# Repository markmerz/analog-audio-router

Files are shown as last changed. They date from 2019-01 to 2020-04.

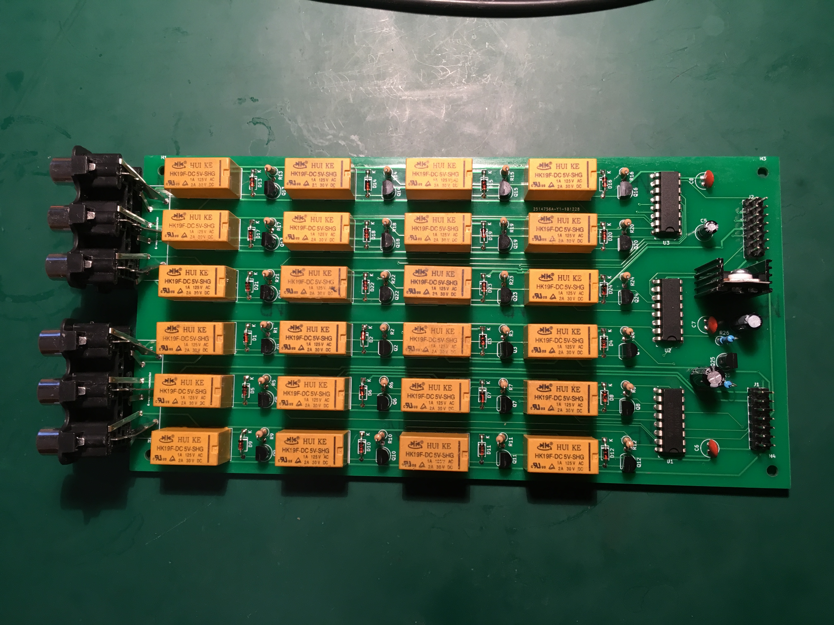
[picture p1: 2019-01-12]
showoff/assembled-audiorouter-board.jpg

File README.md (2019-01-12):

# analog-audio-router
Schematics and firmware for analog line level audio router/switchbox.

When You have some number of older audio gear then inputs count of power amplifier comes an issue. 
It would be nice to have some kind of switchbox for RCA inputs. There is not something like that in
the market, so i'm building one by myself. With blackjack!

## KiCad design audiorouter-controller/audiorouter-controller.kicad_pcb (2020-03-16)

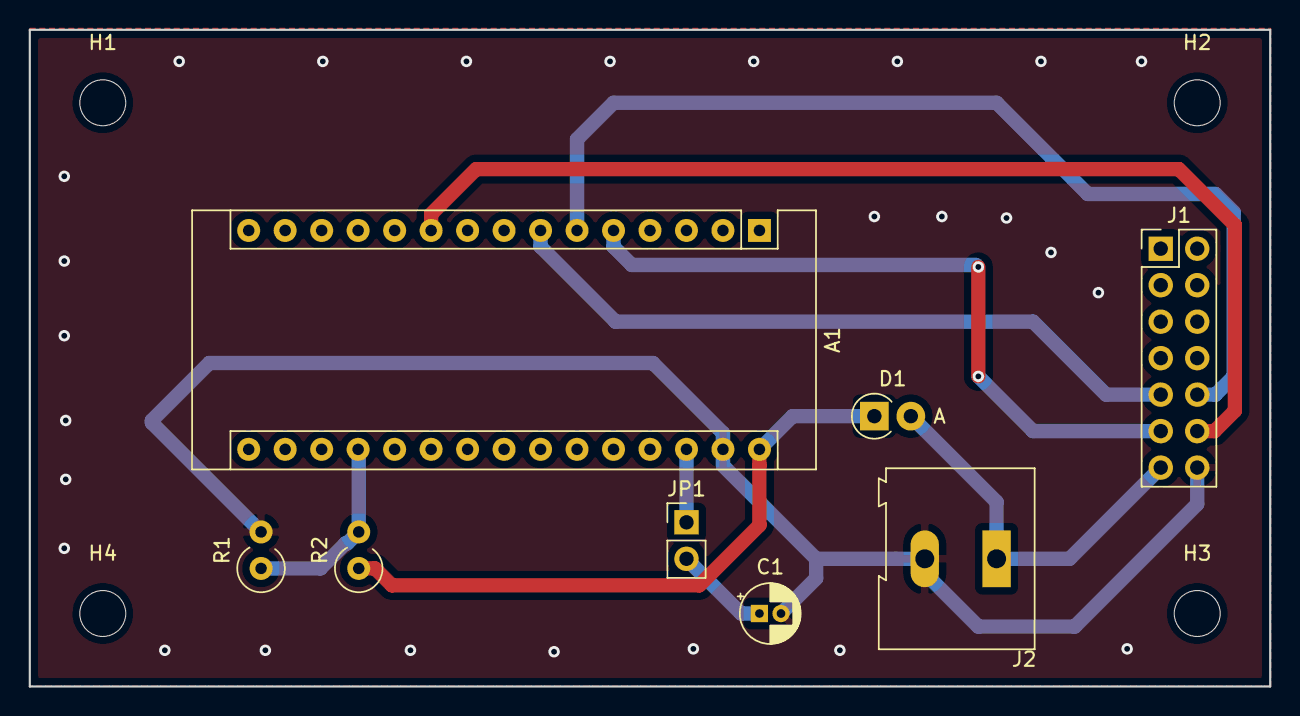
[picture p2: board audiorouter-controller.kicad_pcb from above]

Board: 2 copper layers, 86.4 x 45.7 mm, 12 parts (0 on the bottom side), 10 nets.

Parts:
A1: Arduino_Nano_v3.x; Arduino_Nano
C1: 10u; CP_Radial_D4.0mm_P1.50mm
D1: N4007; D_T-1_P2.54mm_Vertical_AnodeUp
H1, H2, H3, H4: MountingHole; MountingHole_3.2mm_M3
J1: ToBoards; PinHeader_2x07_P2.54mm_Vertical
J2: PowerIn; TerminalBlock_Altech_AK300-2_P5.00mm
JP1: progEnable; PinHeader_1x02_P2.54mm_Vertical
R1, R2: 6.8k; R_Axial_DIN0309_L9.0mm_D3.2mm_P2.54mm_Vertical

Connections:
GND: A1.29, C1.2, J1.14, J2.2, R1.2
unnamed: A1.28, JP1.1
unnamed: A1.30, D1.1, R2.1
unnamed: C1.1, JP1.2
OutputEnable: A1.10, J1.12
PowerIn: D1.2, J1.13, J2.1
PowerMeasure: A1.19, R1.1, R2.2
RClock: A1.6, J1.10
SerialClock: A1.5, J1.11
SerialOut: A1.7, J1.9

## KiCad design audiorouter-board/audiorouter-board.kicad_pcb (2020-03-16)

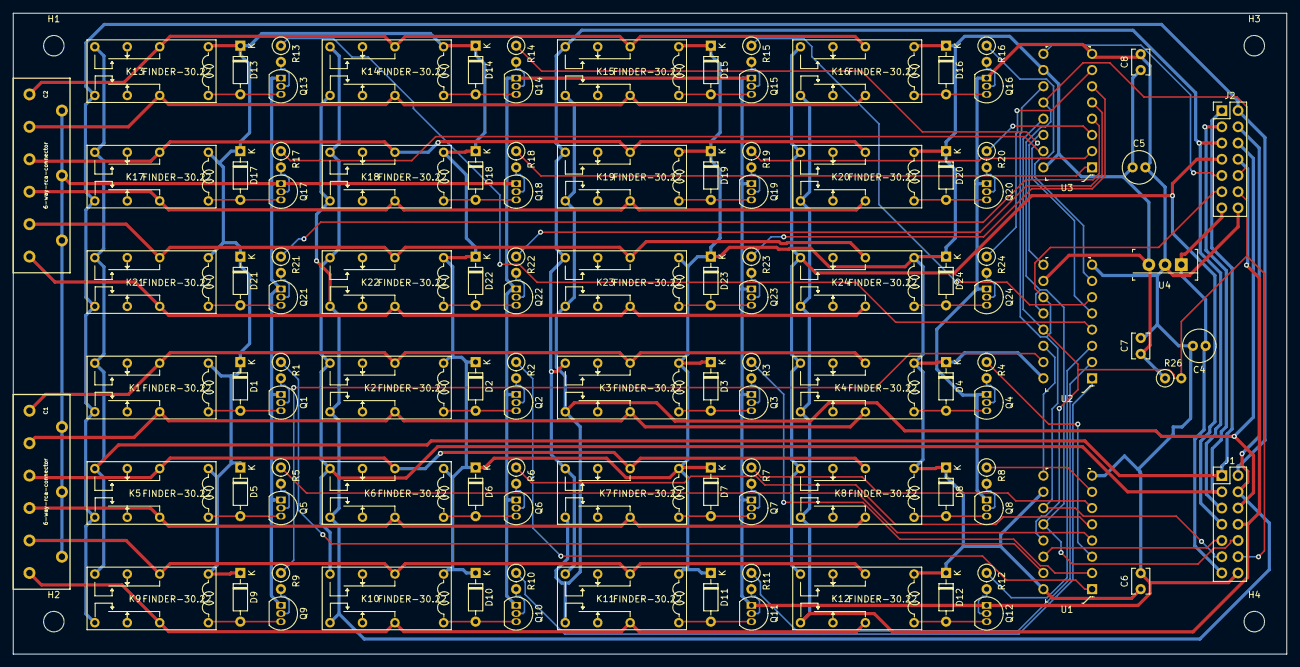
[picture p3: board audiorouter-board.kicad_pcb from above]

Board: 2 copper layers, 199.4 x 100.3 mm, 114 parts (0 on the bottom side), 102 nets.

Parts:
C1, C2: 6-way-rca-connector; 6-way-rca-connector-on-edge
C4, C5: 10u; C_Radial_D5.0mm_H11.0mm_P2.00mm
C6, C7, C8: 10n; C_Disc_D3.8mm_W2.6mm_P2.50mm
D1, D2, D3, D4, D5, D6, D7, D8, D9, D10, D11, D12, D13, D14, D15, D16, D17, D18, D19, D20, D21, D22, D23, D24: 1N914; D_DO-35_SOD27_P7.62mm_Horizontal
H1, H2, H3, H4: MountingHole; MountingHole_3.2mm_M3
J1: Input_Ribbon_Connector; PinHeader_2x07_P2.54mm_Vertical
J2: Output_Ribbon_Connector; PinHeader_2x07_P2.54mm_Vertical
K1, K2, K3, K4, K5, K6, K7, K8, K9, K10, K11, K12, K13, K14, K15, K16, K17, K18, K19, K20, K21, K22, K23, K24: FINDER-30.22; RY12w-k_bigger_holes
Q1, Q2, Q3, Q4, Q5, Q6, Q7, Q8, Q9, Q10, Q11, Q12, Q13, Q14, Q15, Q16, Q17, Q18, Q19, Q20, Q21, Q22, Q23, Q24: PN2222A; TO-92_Inline
R1, R2, R3, R4, R5, R6, R7, R8, R9, R10, R11, R12, R13, R14, R15, R16, R17, R18, R19, R20, R21, R22, R23, R24: 1k; R_Axial_DIN0207_L6.3mm_D2.5mm_P2.54mm_Vertical
R26: 10k; R_Axial_DIN0207_L6.3mm_D2.5mm_P2.54mm_Vertical
U1, U2, U3: 74HC595; DIP-16_W7.62mm
U4: L7805; TO-220-3

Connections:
GND: C1.2, C1.5, C1.8, C2.2, C2.5, C2.8, C4.2, C5.2, C6.2, C7.2, C8.2, J1.14, J2.14, Q1.1, Q2.1, Q3.1, Q4.1, Q5.1, Q6.1, Q7.1, Q8.1, Q9.1, Q10.1, Q11.1, Q12.1, Q13.1, Q14.1, Q15.1, Q16.1, Q17.1, Q18.1, Q19.1, Q20.1, Q21.1, Q22.1, Q23.1, Q24.1, U1.8, U2.8, U3.8, U4.2
IN_1_B_1: R1.1, U1.15
IN_1_B_2: R2.1, U1.1
IN_1_B_3: R3.1, U1.2
IN_1_B_4: R4.1, U1.3
IN_2_B_1: R5.1, U1.4
IN_2_B_2: R6.1, U1.5
IN_2_B_3: R7.1, U1.6
IN_2_B_4: R8.1, U1.7
IN_3_B_1: R9.1, U2.15
IN_3_B_2: R10.1, U2.1
IN_3_B_3: R11.1, U2.2
IN_3_B_4: R12.1, U2.3
IN_4_B_1: R13.1, U2.4
IN_4_B_2: R14.1, U2.5
IN_4_B_3: R15.1, U2.6
IN_4_B_4: R16.1, U2.7
IN_5_B_1: R17.1, U3.15
IN_5_B_2: R18.1, U3.1
IN_5_B_3: R19.1, U3.2
IN_5_B_4: R20.1, U3.3
IN_6_B_1: R21.1, U3.4
IN_6_B_2: R22.1, U3.5
IN_6_B_3: R23.1, U3.6
IN_6_B_4: R24.1, U3.7
unnamed: C1.1, K1.21, K2.21, K3.21, K4.21
unnamed: C1.3, K1.11, K2.11, K3.11, K4.11
unnamed: C1.4, K5.21, K6.21, K7.21, K8.21
unnamed: C1.6, K5.11, K6.11, K7.11, K8.11
unnamed: C1.7, K9.21, K10.21, K11.21, K12.21
unnamed: C1.9, K9.11, K10.11, K11.11, K12.11
unnamed: C2.1, K13.21, K14.21, K15.21, K16.21
unnamed: C2.3, K13.11, K14.11, K15.11, K16.11
unnamed: C2.4, K17.21, K18.21, K19.21, K20.21
unnamed: C2.6, K17.11, K18.11, K19.11, K20.11
unnamed: C2.7, K21.21, K22.21, K23.21, K24.21
unnamed: C2.9, K21.11, K22.11, K23.11, K24.11
unnamed: D1.2, K1.A1, Q1.3
unnamed: D2.2, K2.A1, Q2.3
unnamed: D3.2, K3.A1, Q3.3
unnamed: D4.2, K4.A1, Q4.3
unnamed: D5.2, K5.A1, Q5.3
unnamed: D6.2, K6.A1, Q6.3
unnamed: D7.2, K7.A1, Q7.3
unnamed: D8.2, K8.A1, Q8.3
unnamed: D9.2, K9.A1, Q9.3
unnamed: D10.2, K10.A1, Q10.3
unnamed: D11.2, K11.A1, Q11.3
unnamed: D12.2, K12.A1, Q12.3
unnamed: D13.2, K13.A1, Q13.3
unnamed: D14.2, K14.A1, Q14.3
unnamed: D15.2, K15.A1, Q15.3
unnamed: D16.2, K16.A1, Q16.3
unnamed: D17.2, K17.A1, Q17.3
unnamed: D18.2, K18.A1, Q18.3
unnamed: D19.2, K19.A1, Q19.3
unnamed: D20.2, K20.A1, Q20.3
unnamed: D21.2, K21.A1, Q21.3
unnamed: D22.2, K22.A1, Q22.3
unnamed: D23.2, K23.A1, Q23.3
unnamed: D24.2, K24.A1, Q24.3
unnamed: Q1.2, R1.2
unnamed: Q2.2, R2.2
unnamed: Q3.2, R3.2
unnamed: Q4.2, R4.2
unnamed: Q5.2, R5.2
unnamed: Q6.2, R6.2
unnamed: Q7.2, R7.2
unnamed: Q8.2, R8.2
unnamed: Q9.2, R9.2
unnamed: Q10.2, R10.2
unnamed: Q11.2, R11.2
unnamed: Q12.2, R12.2
unnamed: Q13.2, R13.2
unnamed: Q14.2, R14.2
unnamed: Q15.2, R15.2
unnamed: Q16.2, R16.2
unnamed: Q17.2, R17.2
unnamed: Q18.2, R18.2
unnamed: Q19.2, R19.2
unnamed: Q20.2, R20.2
unnamed: Q21.2, R21.2
unnamed: Q22.2, R22.2
unnamed: Q23.2, R23.2
unnamed: Q24.2, R24.2
unnamed: U1.9, U2.14
unnamed: U2.9, U3.14
OutPutEnable: J1.12, J2.12, R26.2, U1.13, U2.13, U3.13
PowerIn: C4.1, J1.13, J2.13, U4.1
RClock: J1.10, J2.10, U1.12, U2.12, U3.12
SerialClock: J1.11, J2.11, U1.11, U2.11, U3.11
Serial_IN: J1.9, U1.14
Serial_OUT: J2.9, U3.9
VCC: C5.1, C6.1, C7.1, C8.1, D1.1, D2.1, D3.1, D4.1, D5.1, D6.1, D7.1, D8.1, D9.1, D10.1, D11.1, D12.1, D13.1, D14.1, D15.1, D16.1, D17.1, D18.1, D19.1, D20.1, D21.1, D22.1, D23.1, D24.1, K1.A2, K2.A2, K3.A2, K4.A2, K5.A2, K6.A2, K7.A2, K8.A2, K9.A2, K10.A2, K11.A2, K12.A2, K13.A2, K14.A2, K15.A2, K16.A2, K17.A2, K18.A2, K19.A2, K20.A2, K21.A2, K22.A2, K23.A2, K24.A2, R26.1, U1.10, U1.16, U2.10, U2.16, U3.10, U3.16, U4.3
bus_1_L: J1.1, J2.1, K1.24, K5.24, K9.24, K13.24, K17.24, K21.24
bus_1_R: J1.2, J2.2, K1.14, K5.14, K9.14, K13.14, K17.14, K21.14
bus_2_L: J1.3, J2.3, K2.24, K6.24, K10.24, K14.24, K18.24, K22.24
bus_2_R: J1.4, J2.4, K2.14, K6.14, K10.14, K14.14, K18.14, K22.14
bus_3_L: J1.5, J2.5, K3.24, K7.24, K11.24, K15.24, K19.24, K23.24
bus_3_R: J1.6, J2.6, K3.14, K7.14, K11.14, K15.14, K19.14, K23.14
bus_4_L: J1.7, J2.7, K4.24, K8.24, K12.24, K16.24, K20.24, K24.24
bus_4_R: J1.8, J2.8, K4.14, K8.14, K12.14, K16.14, K20.14, K24.14

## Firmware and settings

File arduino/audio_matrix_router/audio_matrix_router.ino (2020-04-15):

#include <string.h>
#include <stdio.h>

//These define's must be placed at the beginning before #include "TimerInterrupt.h"
#define TIMER_INTERRUPT_DEBUG      0

#define USE_TIMER_1     true
#define USE_TIMER_2     false
#define USE_TIMER_3     false
#define USE_TIMER_4     false
#define USE_TIMER_5     false

#include "TimerInterrupt.h"

#define NUM_BOARDS 4 // nr of connected boards
int latchPin = 3; // r clock
int clockPin = 2; // serial clock
int dataPin = 4;  // serial data
int outputEnable = 7; // 595 output enable pins are pulled high (disabled) in hardware. We need to pull it down (enable) when ready.

#define COMMAND_LINE_BUFFER_LEN 64

// i messed up component placement on board
// it amazing what you can fix in software later..
const uint8_t chips[6][4] = {{1, 1, 1, 1}, {0, 0, 0, 0}, {0, 0, 0, 0}, {2, 2, 2, 2}, {2, 2, 2, 2}, {1, 1, 1, 1}};
const uint8_t values[6][4] = {{8, 4, 2, 1}, {128, 64, 32, 16}, {8, 4, 2, 1}, {128, 64, 32, 16}, {8, 4, 2, 1}, {128, 64, 32, 16}};

uint8_t state[NUM_BOARDS][3];
char inData[COMMAND_LINE_BUFFER_LEN];
uint8_t inDataIndex = 0;

uint16_t pingCounter = 0;
uint8_t powerState = 0;
uint8_t inTransition = 0;

void myShiftOut(uint8_t dataPin, uint8_t clockPin, uint8_t bitOrder, byte val) {
  for (int i = 0; i < 8; i++) {
    if (bitOrder == LSBFIRST) {
      digitalWrite(dataPin, !!(val & (1 << i)));
      delayMicroseconds(50);
    } else {
      digitalWrite(dataPin, !!(val & (1 << (7 - i))));
      delayMicroseconds(50);
    }

    digitalWrite(clockPin, HIGH);
    delayMicroseconds(50);
    digitalWrite(clockPin, LOW);
    delayMicroseconds(50);
  }
}



void writeState() {
  for (int c = 0; c < NUM_BOARDS; c++) {
    for (int d = 0; d < 3; d++) {
      myShiftOut(dataPin, clockPin, LSBFIRST, state[c][d]);
    }
  }
  digitalWrite(latchPin, HIGH);
  delayMicroseconds(50);
  digitalWrite(latchPin, LOW);
  inTransition = 0;
}

void clearState() {
  for (int c = 0; c < NUM_BOARDS; c++) {
    state[c][0] = state[c][1] = state[c][2] = 0;
  }
}

inline uint8_t countSetBits(uint8_t n) { // Brian Kernighan’s Algorithm
  uint8_t count = 0;
  while (n) {
    n &= (n - 1);
    count++;
  }
  return count;
}

int testState() {
  unsigned int bitcount = 0;
  for (int c = 0; c < NUM_BOARDS; c++) {
    for (int d = 0; d < 3; d++) {
      bitcount += countSetBits(state[c][d]);
    }
  }
  if (bitcount > 16) {
    return 0;
  }
  return 1;
}

void handleInput() {
  if (strcmp(inData, "clear") == 0) {
    inTransition = 1;
    clearState();
    Serial.write("OK\n");
  } else if (strcmp(inData, "commit") == 0) {
    if (powerState) {
      if (testState()) {
        writeState();
        Serial.write("OK\n");
      } else {
        Serial.write("ERROR: not commiting too many connections.\n"); // because power module from ebay might expode!
      }
    } else {
      Serial.write("ERROR: not commiting, daughter boards are not powered.\n");
    }
  } else if (strncmp(inData, "sethard ", 8) == 0) {
    int board, chip, value;
    int res = sscanf(inData, "sethard %i %i %i", &board, &chip, &value);
    if (res == 3) {
      inTransition = 1;
      state[board][chip] = value;
      Serial.write("OK\n");
    } else {
      Serial.write("ERROR: sethard parse error: ");
      Serial.print(res);
      Serial.write("\n");
    }
  } else if (strncmp(inData, "connect ", 8) == 0) {
    int connector, bus;
    int res = sscanf(inData, "connect %i bus %i", &connector, &bus);
    if (res == 2) {
      if (connector < 1 || connector > (NUM_BOARDS * 6)) {
        Serial.write("ERROR: connect parse error: connector nr. out of bounds.\n");
      } else if (bus < 1 || bus > 4) {
        Serial.write("ERROR: connect parse error: bus nr. out of bounds.\n");
      } else {
        inTransition = 1;
        connector = connector - 1;
        bus = bus - 1;
        uint8_t board = connector / 6;
        connector = connector % 6;
        uint8_t chip = chips[connector][bus];
        uint8_t value = values[connector][bus];
        state[board][chip] = state[board][chip] | value;
        Serial.write("OK\n");
      }
    } else {
      Serial.write("ERROR: connect parse error: ");
      Serial.print(res);
      Serial.write("\n");
    }
  } else if (strncmp(inData, "disconnect ", 11) == 0) {
    int connector, bus;
    int res = sscanf(inData, "disconnect %i bus %i", &connector, &bus);
    if (res == 2) {
      if (connector < 1 || connector > (NUM_BOARDS * 6)) {
        Serial.write("ERROR: disconnect parse error: connector nr. out of bounds.\n");
      } else if (bus < 1 || bus > 4) {
        Serial.write("ERROR: disconnect parse error: bus nr. out of bounds.\n");
      } else {
        inTransition = 1;
        connector = connector - 1;
        bus = bus - 1;
        uint8_t board = connector / 6;
        connector = connector % 6;
        uint8_t chip = chips[connector][bus];
        uint8_t value = values[connector][bus];
        state[board][chip] = state[board][chip] & (~value);
        Serial.write("OK\n");
      }
    } else {
      Serial.write("ERROR: disconnect parse error: ");
      Serial.print(res);
      Serial.write("\n");
    }
  } else if (strcmp(inData, "ping") == 0) {
    Serial.write("Audio Switch OK\n");
  } else if (strcmp(inData, "test_count") == 0) {
    Serial.write("Test counter: ");
    Serial.print(pingCounter);
    Serial.write("\n");
    pingCounter++;
  } else if (strcmp(inData, "power") == 0) {
    int power = analogRead(A0);
    Serial.write("Power reading: ");
    Serial.print(power);
    Serial.write("\n");
  } else {
    Serial.write("ERROR: Unknown command: ");
    Serial.write(inData);
    Serial.write("\n");
  }
}

void setup() {
  pinMode(latchPin, OUTPUT);
  pinMode(clockPin, OUTPUT);
  pinMode(dataPin, OUTPUT);

  pinMode(outputEnable, INPUT); // to Z-mode. Hardware has pullups.

  pinMode(LED_BUILTIN, OUTPUT); // led is on when running on external power

  clearState();

  ITimer1.init();
  ITimer1.attachInterruptInterval(1000, TimerHandler1); // timer fires once in a second

  Serial.begin(115200);
  while (!Serial) {}
  //  Serial.print(NUM_BOARDS);
  //  Serial.write(" boards ready\n");
}

void checkPower() {
  int power = analogRead(A0);

#define VOLTAGE10V 740

  if (powerState) { // when incoming power is less then 10V then we set 595 output enable pins high disabling them
    if (power < VOLTAGE10V) {
      // digitalWrite(outputEnable, HIGH);
      pinMode(outputEnable, INPUT); // Go to Z-mode. Hardware pulls line up.
      clearState();
      powerState = 0;
      digitalWrite(LED_BUILTIN, LOW);
    }
  } else {
    if (power >= VOLTAGE10V) {
      clearState();
      writeState();
      powerState = 1;
      pinMode(outputEnable, OUTPUT);
      digitalWrite(outputEnable, LOW); // pull line low.
      digitalWrite(LED_BUILTIN, HIGH);
    }
  }


}

void TimerHandler1(void) {
  checkPower();
  // we rewrite our state regulary to work around intermittent errors because electrical noise. It is a hardware design error somewhere.
  if (inTransition == 0 && powerState == 1) {
    writeState();
  }
}

void loop() {
  if (Serial.available() > 0) {
    if (inDataIndex < (COMMAND_LINE_BUFFER_LEN)) {
      inData[inDataIndex] = Serial.read();
      if (inData[inDataIndex] == '\n') {
        inData[inDataIndex] = '\0';
        handleInput();
        inDataIndex = 0;
      } else {
        inDataIndex++;
      }
    } else {
      inDataIndex = 0;
      Serial.write("ERROR: Buffer full, input rejected.\n");
    }
  }

}

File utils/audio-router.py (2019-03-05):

#!/usr/bin/python3

import glob
import serial
import sys
import termios

def main():
    try:
        if sys.argv[1] == "find":
            find()            
        else:
            device = sys.argv[1]
            command = " ".join(sys.argv[2:])
            command += "\n"        
            with serial.Serial(device, 115200, timeout=2, dsrdtr=False) as ser:
                ser.write(command.encode("latin-1"))
                res = ser.readline().decode("latin-1")
                print(res, end='')
        
    except IndexError:
        print("Usage: {} (find | device [commands to board])".format(sys.argv[0]), file=sys.stderr)
        sys.exit(1)

def find():
    for device_candidate in glob.glob("/dev/ttyUSB*"):
        do_retry = True
        retry_count = 3
        while do_retry and retry_count > 0:
            do_retry = False
            try:
                with serial.Serial(device_candidate, 115200, timeout=2, dsrdtr=False) as ser:
                    ser.write(b'\n')
                    while True:
                        res = ser.read(10)
                        if len(res) == 0:
                            break
                    ser.write(b'ping\n')
                    res = ser.readline().decode("latin-1")
                    if res == "Audio Switch OK\n":
                        print(device_candidate)
                        return
            except serial.serialutil.SerialException:
                do_retry = True
                retry_count -= 1

    else:
        print("Device was not found.", file=sys.stderr)
        sys.exit(1)

if __name__ == "__main__":
    main()

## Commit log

2019-03-05 Changes and bodges.
    [audiorouter-controller.kicad_pcb, audiorouter-controller.sch]
2020-03-16 Turned out that time delay circut for 595 output enable pins was bad idea in practice. I reworked my device by removing timed pull-down circuit components while leaving pull-up in place. Added wires 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
    Rewrote controller board arduino software for output enable logic.
    Fixed bugs that caused parasitic powering of daughter boards via
    595 data pins. Worked around noise induced false triggering by
    overwriting correct state to 595 cascade every second. Added
    software logic for drawn current limiting.
    [audiorouter-board.kicad_pcb, audiorouter-board.sch, audiorouter-controller.kicad_pcb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]
2020-04-15 Bugfixes for power management.
    [audio_matrix_router.ino]
